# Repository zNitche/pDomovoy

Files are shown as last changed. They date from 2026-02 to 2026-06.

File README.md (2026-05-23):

# pDomovoy

pDomovoy (pD) - room intrusion detection system

### Description
Some time ago I built a [sleepwalking detection and prevention system](https://github.com/zNitche/sleepwalker). It served its purpose good but extensive setup (smartwatch + raspberry Pi 4 + wiring) and the fact that in previous years I've traveled a lot and stayed at many different hotels made me rethink that design.

Then this idea came to my mind, dedicated devices, with long lasting battery life, travel safe (no strong magnets, detachable battery), that serves as `sleepwalker` did but also provides a way to make sure your room's doors stays closed when you sleep (in short nobody enters and leaves without triggering the alarm).

So let's build 2 devices system connected via BLE using C and `pico-sdk`.

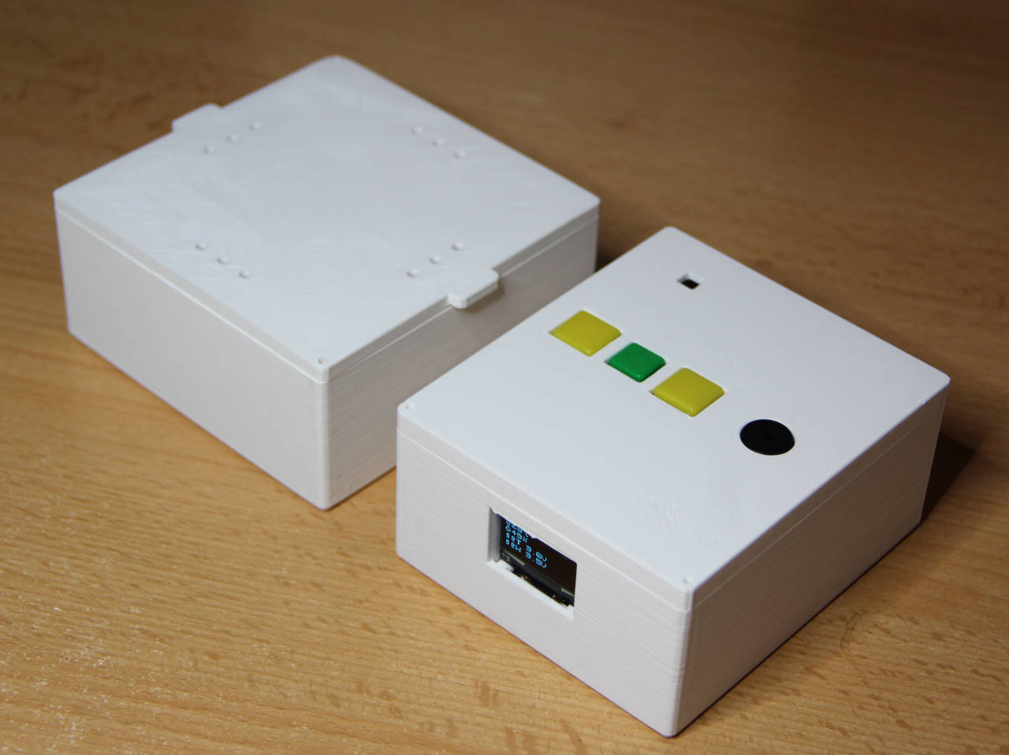
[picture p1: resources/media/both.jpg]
both


### Modules breakdown

#### Warden

##### Description
Heavy lifting device, after initialization (by button push or `Trumpet`) placed against the door, if device's position / orientation changes (or if paired with `trumpet` and connection is lost), the alarm will be activated.

Triggered alarm can by disabled by:
- pushing button 5 times
- using `Trumpet's` control panel

##### Assembly
Setup is quite simple, but due to lack of my PCB production capacities, everything had to be assembled using prototype boards + point to point wiring, anyway it looks like this:

- 2x 30x70 mm prototype 2-side boards, some wires, socket for glass tube fuse and cell holder for 18650 battery

- TP4056 (with DW01a for cell protection) for 18650 LI-ION charging (connected via 1A fuse)
- LED and buzzer connected via BC337 transistor for 5V supply and 3.3V control line, connected via 440R resistor to Raspberry Pi Pico W (probably should add 3.3V zener diode to logic line as a extra protection, but due to reasons mentioned earlier I did not)
- Button connected via 440R resistor to MCU
- 2k2 + 2k2 resistors as voltage divider (with ratio 1/2) connected to battery and MCU ADC as voltmeter used for checking battery level
- ADXL345 accelerometer connected to RPI Pico's 3.3V line and I2C 1
- MCU powered via 5V step-up DC converter
- 220uF capacitors added to Pico's 5V input & step-up converter's input
- 1uF capacior added in parrel to the buzzer for eliminating voltage spikes while generating tone

- 3D printed case, circuit boards mounted using 4x 2mm and 4x 3mm screws
- 2x 2mm screws for case closing

##### Photos
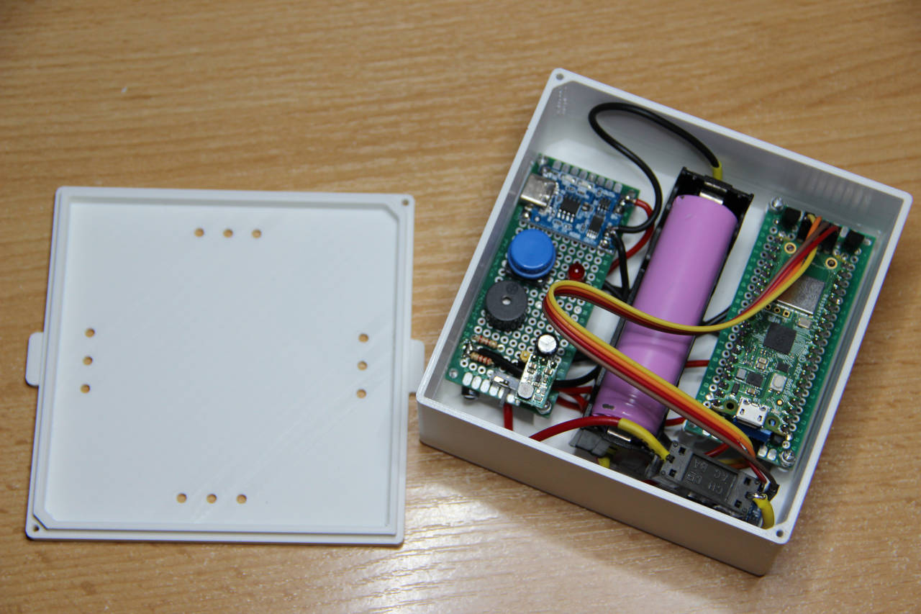
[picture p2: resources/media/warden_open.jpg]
warden_open


#### Trumped
##### Description
Remote panel for whole system with buttons controls and oled display

###### Features
- secure communication with `warden` over BLE with MAC addresses filtering
- `warden's` alarm state management & data preview (battery voltage & alarm state)
- AHT20 humidity & temperature readings
- built in buzzer for alarm
- integrated with SSD1306 screen for data presentation

###### Display pages
1. home page

- aht20 based temperature & humidity
- `trumpet's` & `warden's` battery voltage
- alarm state

2. time stats page

- time since boot
- time since `warden` has been connected
- time since alarm has been armed

3. versions page

shows `trumpet's` & `warden's` version (if `warden` is connected)

###### trumpet's alarm
`trumpet` is equiped with built in buzzer serving as alarm (the same 5v powered buzzer as in `warden`), it will be activated in below cases:

- `warden's` alarm is triggered
- `warden's` alarm in in standby mode and it's connection with `trumpet` has been lost

##### Assembly
the same situation as in `warden's` case, good old prototype boards + point to point wiring, setup looks like this:

- 1x 60x80 mm + 1x 20x80 mm prototype 2-side boards, some wires, socket for glass tube fuse and cell holder for 18650 battery

- TP4056 (with DW01a for cell protection) for 18650 LI-ION charging (connected via 1A fuse)
- Alarm buzzer connected via BC337 transistor for 5V supply and 3.3V control line, connected via 330R resistor to MCU
- 10uF capacior (should be 1uF as in `warden` but due to mistake it is what it is) added in parrel to the buzzer for eliminating voltage spikes while generating tone
- Buttons connected via 330R resistors to MCU
- display & temperature sensor connected to i2c0 and powered via MCU's internal 3.3v
- 1k + 3k3 resistors as voltage divider (with ratio 0.75) connected to battery and MCU ADC as voltmeter used for checking battery level
- MCU powered via 5V step-up DC converter
- 220uF capacitors added to Pico's 5V input & step-up converter's input
- 3D printed case, circuit boards mounted using 10x 2mm and 2x 3mm screws

##### Photos
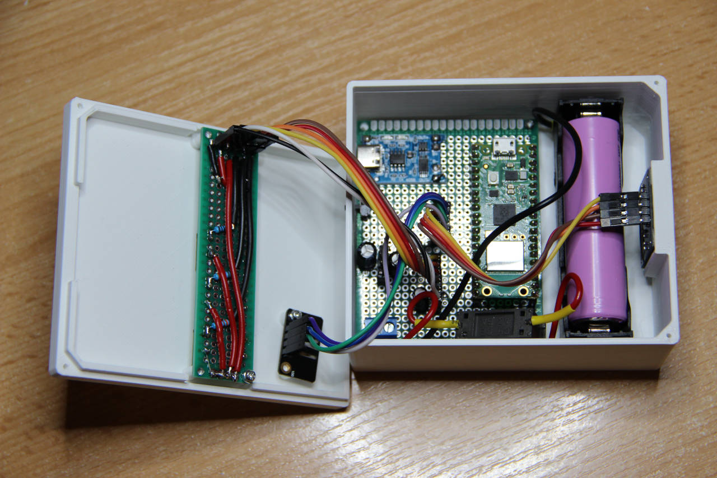
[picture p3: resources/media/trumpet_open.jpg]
trumpet_open


### Setup

1. get pico-sdk
```
mkdir -p ~/SDKs/pico-sdk
cd ~/SDKs/pico-sdk
git clone -b "2.2.0" --single-branch https://github.com/raspberrypi/pico-sdk.git 2.2.0
```

2. initialize pico-sdk dependencies
```
cd ~/SDKs/pico-sdk/2.2.0
git submodule update --init
```

3. initialize project dependencies
```
git submodule update --init
```

4. config setup

###### create config.cmake
```
cp config.cmake.template config.cmake
```

###### fill it's content (if using warden & trumpet)

- set PD_WARDEN_BT_MODE_ENABLED to true
- set PD_WARDEN_BT_MAC to warden's MAC address
- set PD_TRUMPET_BT_MAC to warden's MAC address

5. open project in devcontainer
6. setup project

```
cmake -S . -B build
```

or for debug mode

```
cmake -DDEBUG=1 -S . -B build
```

7. build
```
cd build
make
```

8. flash device with generated `.uf2` file (`trumpet` / `warden`)

### Extra

#### auto copying of `.uf2` file to MCU.
```
sh copy_uf2.sh ./build/warden.uf2 /Volumes/RPI-RP2
```

#### Connect to device
```
screen /dev/tty1
```

to exit 
```
CTRL + A -> CTRL + \
```

### Dependencies
- [pico-sdk](https://github.com/raspberrypi/pico-sdk)

- [ADXL345](https://github.com/zNitche/pico-c-adxl345)
- [SSD1306](https://github.com/zNitche/pico-c-ssd1306)
- [AHT20](https://github.com/zNitche/pico-c-aht20)

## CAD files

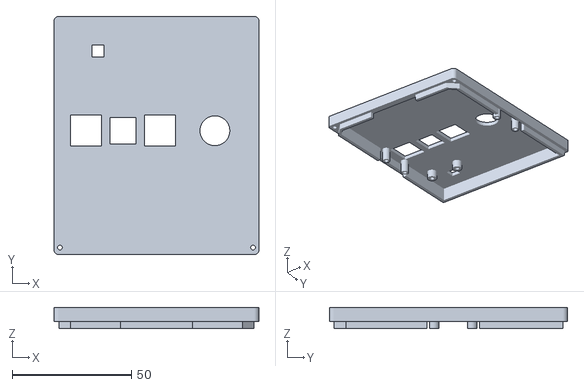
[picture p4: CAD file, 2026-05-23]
resources/3d_models/trumpet/top_mk1.stl
86.0 x 100.0 x 9.00

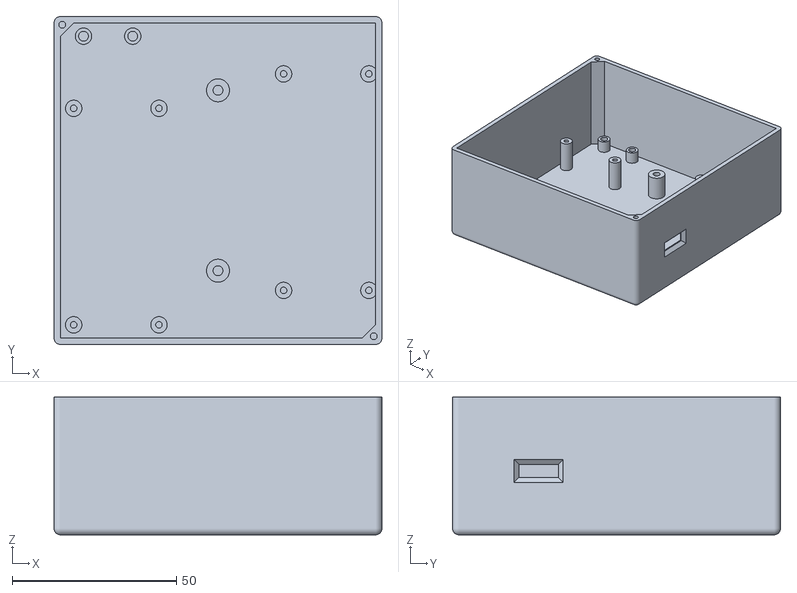
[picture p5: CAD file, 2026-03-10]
resources/3d_models/warden/case_mk2.stl
100.0 x 100.0 x 42.0

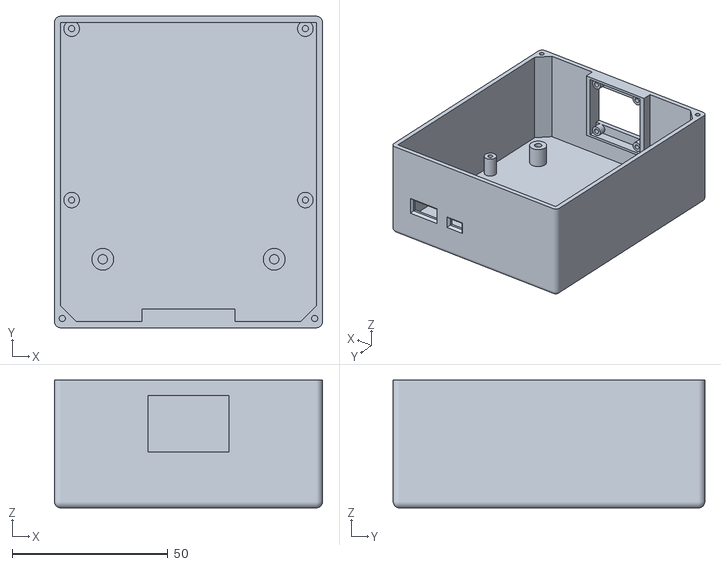
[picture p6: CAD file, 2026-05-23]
resources/3d_models/trumpet/bottom_mk1.stl
86.0 x 100.0 x 41.0

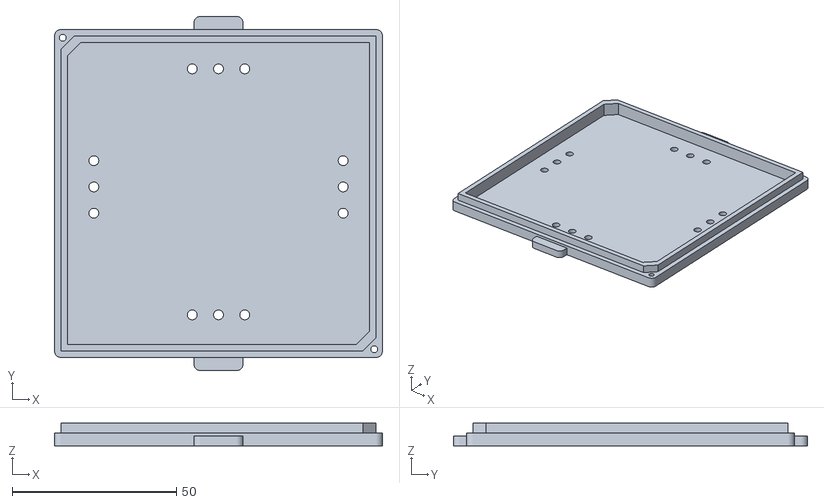
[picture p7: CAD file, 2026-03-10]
resources/3d_models/warden/top_cover_mk2.stl
100.0 x 108.0 x 7.00

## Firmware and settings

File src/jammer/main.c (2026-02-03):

#include <stdio.h>

#include "pico_adxl345/adxl345.h"
#include "hardware/gpio.h"
#include "hardware/pwm.h"
#include "pico/cyw43_arch.h"
#include "pico/stdlib.h"

const int STATUS_LED_PIN = 13;
const int BUZZER_PIN = 14;
const int ACTION_BUTTON_PIN = 12;

bool alarm_on = false;

void buzzer_pwm_call_irq() {
  static int fade = 0;
  static bool going_up = true;

  pwm_clear_irq(pwm_gpio_to_slice_num(BUZZER_PIN));

  if (going_up) {
    ++fade;
    if (fade > 255) {
      fade = 255;
      going_up = false;
    }
  } else {
    --fade;
    if (fade < 0) {
      fade = 0;
      going_up = true;
    }
  }

  pwm_set_gpio_level(BUZZER_PIN, fade * fade);
}

void init_buzzer_pwm() {
  gpio_set_function(BUZZER_PIN, GPIO_FUNC_PWM);
  uint slice_num = pwm_gpio_to_slice_num(BUZZER_PIN);

  pwm_clear_irq(slice_num);
  irq_set_exclusive_handler(PWM_DEFAULT_IRQ_NUM(), buzzer_pwm_call_irq);

  pwm_config config = pwm_get_default_config();
  pwm_config_set_clkdiv(&config, 1);
  pwm_init(slice_num, &config, true);
}

void enable_buzzer_pwm() {
  uint slice_num = pwm_gpio_to_slice_num(BUZZER_PIN);

  irq_set_enabled(PWM_DEFAULT_IRQ_NUM(), true);
  pwm_set_irq_enabled(slice_num, true);
}

void disable_buzzer_pwm() {
  uint slice_num = pwm_gpio_to_slice_num(BUZZER_PIN);

  irq_set_enabled(PWM_DEFAULT_IRQ_NUM(), false);
  pwm_set_irq_enabled(slice_num, false);
  pwm_set_gpio_level(BUZZER_PIN, 0);
}

void button_callback(uint gpio, uint32_t events) {
  if (gpio == ACTION_BUTTON_PIN) {
    if (events == 8) {
      printf("alarm trigger\n");

      if (alarm_on) {
        disable_buzzer_pwm();
        alarm_on = false;
      } else {
        enable_buzzer_pwm();
        alarm_on = true;
      }
    }
  }
}

int main() {
  stdio_init_all();

  int rc = cyw43_arch_init();
  hard_assert(rc == PICO_OK);

#ifdef DEBUG
  // waiting for input
  getchar();
#endif

  printf("jammer...\n");

  // BUZZER
  init_buzzer_pwm();

  // BUTTON
  gpio_init(ACTION_BUTTON_PIN);
  gpio_set_dir(ACTION_BUTTON_PIN, GPIO_IN);
  gpio_pull_down(ACTION_BUTTON_PIN);
  gpio_set_irq_enabled_with_callback(ACTION_BUTTON_PIN, GPIO_IRQ_EDGE_RISE,
                                     true, &button_callback);

  // LED
  gpio_init(STATUS_LED_PIN);
  gpio_set_dir(STATUS_LED_PIN, true);

  // ADXL345
  ADXL345I2C adxl345_i2c = {i2c0, 0x53, 0, 1};

  adxl345_setup_i2c(adxl345_i2c);
  sleep_ms(250);

  bool connected = adxl345_check_connection(adxl345_i2c);

  printf("connected: %d\n", connected);

  enum ADXL345Ranges sensor_range = RANGE_4G;
  adxl345_set_measurements_range(adxl345_i2c, sensor_range);

  adxl345_start_measurements(adxl345_i2c);

  while (true) {
    gpio_put(STATUS_LED_PIN, true);
    sleep_ms(250);
    gpio_put(STATUS_LED_PIN, false);
    sleep_ms(250);

    if (connected) {
      float accel[3] = {0.0};
      adxl345_get_readings(adxl345_i2c, accel);

      printf("Acc. X = %f, Y = %f, Z = %f\n", accel[0], accel[1], accel[2]);

      sleep_ms(200);
    }
  }

  adxl345_stop_measurements(adxl345_i2c);

  return 0;
}

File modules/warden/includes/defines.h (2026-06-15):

#pragma once

#ifndef DEBUG
#define DEBUG 0
#endif

#define PD_WAIT_FOR_ALARM_ARM 15

#define PD_ACCELERATION_CHANGE_TRIGGER_FACTOR 0.3
#define PD_ACCELERATION_READINGS_COUNT 15
#define PD_ACCELERATION_READINGS_DELAY 100

#define PD_ACCELERATION_INITIAL_READINGS_COUNT 15
#define PD_ACCELERATION_INITIAL_READINGS_DELAY 200

// pins
#define PD_ADXL345_SDA_PIN 0
#define PD_ADXL345_SCL_PIN 1
#define PD_STATUS_LED_PIN 15
#define PD_BUZZER_PIN 16
#define PD_ACTION_BUTTON_PIN 18
#define PD_VOLTMETER_ADC_PIN 28
#define PD_VOLTMETER_ADC_ID 2

// button actions
#define CLICK_DEBOUNCE_TIME 1000

#define MIN_TIME_BETWEEN_CLICKS_FOR_ACTION 1500
#define CONTINOUS_CLICKS_TO_DISABLE_ALARM 5

// battery stats
#define BATTER_VOLTAGE_READINGS 30
#define MIN_BATTERY_VOLTAGE 3.3

// alarm buzzer
// tweaked to my buzzers, might need additional tweaks for different ones
#define PD_ALARM_BUZZER_DELAY_MS 300
#define PD_ALARM_BUZZER_ACTIVE_TIME_MS 100
#define PD_ALARM_BUZZER_HIGH_VALUE 2500
#define PD_ALARM_BUZZER_HIGH_VALUE_DEBUG 1000

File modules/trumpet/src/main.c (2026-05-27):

#include <stdbool.h>

#include "../includes/callbacks.h"
#include "../includes/core_0.h"
#include "../includes/defines.h"
#include "../includes/globals.h"
#include "../includes/voltmeter.h"
#include "../includes/bluetooth/core.h"
#include "hardware/adc.h"
#include "pdomovoy_common/button.h"
#include "pdomovoy_common/bluetooth.h"
#include "pdomovoy_common/debug_print.h"
#include "pdomovoy_common/pwm.h"
#include "pdomovoy_common/version.h"
#include "pdomovoy_common/voltmeter.h"
#include "pico/cyw43_arch.h"
#include "pico/stdlib.h"

void init_gpio_peripherals() {
     // BUZZER
    setup_alarm_pwm_irq_callback(PD_BUZZER_PIN, alarm_buzzer_irq_callback);

    // NAVIGATION BUTTONS
    init_button_irq(PD_PREVIOUS_BUTTON_PIN, true);
    init_button_irq(PD_APPLY_BUTTON_PIN, true);
    init_button_irq(PD_NEXT_BUTTON_PIN, true);

    gpio_set_irq_callback(&gpio_irq_callback);
}

void init_voltmeter() {
    init_adc_voltmeter(PD_VOLTMETER_ADC_PIN);
    start_voltmeter_bg();
}

int main() {
    stdio_init_all();

    if (DEBUG) {
        // DEBUG waiting for input
        getchar();
    }

    if (cyw43_arch_init()) {
        printf("failed to initialise cyw43\n");
        return 1;
    }

    debug_print("[pD - TRUMPET] %s\n", TRUMPET_VERSION);

    adc_init();

    init_gpio_peripherals();
    init_voltmeter();

    init_ble();
    turn_bluetooth_on();

    // core_0 for device handling
    core_0();

    return 0;
}

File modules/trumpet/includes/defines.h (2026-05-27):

#pragma once

#ifndef DEBUG
#define DEBUG 0
#endif

// display
#define PD_SCREEN_SAVER_AFTER 20000

// pins
#define PD_PREVIOUS_BUTTON_PIN 17
#define PD_APPLY_BUTTON_PIN 16
#define PD_NEXT_BUTTON_PIN 14

#define PD_VOLTMETER_ADC_PIN 28
#define PD_VOLTMETER_ADC_ID 2
#define PD_BUZZER_PIN 18

// i2c
#define PD_AHT20_I2C i2c0
#define PD_AHT20_SDA_PIN 0
#define PD_AHT20_SCL_PIN 1

#define PD_SSD1306_I2C i2c0
#define PD_SSD1306_SDA_PIN 0
#define PD_SSD1306_SCL_PIN 1

// button actions
#define CLICK_DEBOUNCE_TIME 1000

#define MIN_TIME_BETWEEN_CLICKS_FOR_ACTION 1500

// alarm buzzer
#define PD_ALARM_BUZZER_DELAY_MS 600
#define PD_ALARM_BUZZER_ACTIVE_TIME_MS 300

// intended to be placed next to bed, keep it quiet (I used 10uF capacitor
// instead of 1uF), therefore a higher value
#define PD_ALARM_BUZZER_HIGH_VALUE 8500
#define PD_ALARM_BUZZER_HIGH_VALUE_DEBUG 2000

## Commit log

2026-01-15 build: pico sdk setup
2026-02-01 build: added pico-c-adxl345 as git submodule
2026-02-01 feat: added pico-c-adxl345 lib
2026-02-02 fix: proper directory of station -> main.c
    [main.c]
2026-02-02 feat: basic support for button, accelerometer & led
2026-02-02 feat: enabled adxl345 for jammer
    [main.c]
2026-02-03 refactor: moved jammer & station to modules directory
    [main.c]
2026-02-04 feat: jammer - split project into separated files
    [button.c, main.c]
2026-02-04 feat: jammer - added action button callbacks with debounce
    [button.c, callbacks.c, main.c]
2026-02-04 fix: jammer - button callback imports tweaks
    [main.c]
2026-02-04 refactor: extracted buzzer to separated .c file
    [buzzer.c, main.c]
2026-02-05 fix: fixed setting buzzer irq
    [buzzer.c, callbacks.c, main.c]
2026-02-05 refactor: buzzer.c internal cleanup
    [buzzer.c]
2026-02-05 fix: action_button_callback - setting alarm state
    [callbacks.c]
2026-02-05 feat: proper buzzer initialization
    [callbacks.c, main.c]
2026-02-06 refactor: utils - renamed buzzer to pwm
    [callbacks.c, main.c, pwm.c]
2026-02-07 fix: main.c & core_0.c - added missing includes
    [main.c]
2026-02-09 refactor: moved count_clicks_in_row() to button.c
2026-02-10 build: libs - updated pico-c-adxl345 to v1.2.0
2026-02-10 refactor: DeviceStatus items - naming changes
2026-02-10 feat: blocking led blink
2026-02-10 refactor: jammer - renamed handlers.c -> delegates.c
    [callbacks.c]
2026-02-10 feat: led_blink - background bliks using timers
2026-02-10 feat: jammer - core_1 - status led for standby init
    [callbacks.c]
2026-02-10 refactor: moved led_blink.c to utils dir
2026-02-11 refactor: removed status led logic from core_1
2026-02-11 feat: led_blink.c - blink_untill_start() - added init guard
2026-02-11 feat: jammer - alarm_buzzer_irq_callback() proper implementation
    [callbacks.c]
2026-02-12 feat: jammer - switch to pico_cyw43_arch_lwip_threadsafe_background
2026-02-12 feat: jammer - status led blinks
    [button.c, callbacks.c, globals.c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]
2026-02-12 feat: jammer - basic background battery voltmeter
    [globals.c, main.c]
2026-02-17 feat: leds - reclaim blink timer on init
2026-02-17 feat: jammer - blink status led on adxl345 error
2026-02-17 feat: checking battery level + status led integration
2026-02-17 refactor: jammer - extracted battery checking to separated func
2026-02-17 refactor: jammer - status led blink (bg) handling refactoring
2026-02-17 feat: jammer - status led blinks improvements
    [globals.c]
2026-02-17 refactor: jammer - core_0 - moved battery related vars to globals
    [globals.c]
2026-02-19 refactor: jammer - callbacks related typing tweaks
    [callbacks.c]
2026-02-19 fix: cancelling currently running status led timer for blocking blinks
2026-02-22 feat: extracted adxl345 i2c related pins to defines
2026-02-22 feat: moved voltmeter related magic numbers to defines
2026-02-22 refactor: changed pins bindings
    [defines.h]
2026-02-23 feat: battery level checking improvements
2026-02-23 feat: jammer - callbacks.c - logging improvements
    [callbacks.c]
2026-02-24 fix: debug_print() - replaced printf with vprintf
2026-02-24 feat: jammer - version.h
    [main.c]
2026-02-24 refactor: renamed jammer to warden
    [button.c, callbacks.c]
2026-02-27 refactor: removed blocking delay from onboard led blink interrupt
2026-03-08 fix: _blink_onboard_led_cb() setting proper led state
2026-03-09 refactor: warden - changed accelerometer readings for alarm trigger
2026-03-09 feat: core_1 - checkign for accelerometer based alarm trigger improvements
2026-03-10 feat: warden - added 3d models
    [case_mk2.stl, top_cover_mk2.stl]
2026-03-10 feat: added accelerometer_reading type
2026-03-10 refactor: changed array based acceleration reading representation with accelerometer_reading
2026-03-11 refactor: changed root directory of 3d models
    [case_mk2.stl, top_cover_mk2.stl]
2026-04-12 feat: added pico-c-ssd1306 lib as submodule
2026-04-18 feat: added pico-c-aht20 lib as submodule
2026-04-18 build: updated pico-c-adxl345 to v1.2.2
2026-04-19 feat: trumpet basic action button setup
2026-04-19 feat: ButtonDebounceCtx
2026-04-19 refactor: renamed accelerometer_reading to AccelerometerReading
2026-04-20 refactor: removed button_callback type
2026-04-20 refactor: commons - extracted setting gpio irq for button callback
2026-04-20 feat: trumpet - action buttons callbacks
2026-04-21 build: updated pico-c-ssd1306 to v1.0.2
2026-04-21 feat: trumpet - i2c devices initialization utils
2026-04-21 feat: trumpet - core0 screen & aht20 sensor usage
2026-04-21 feat: trumpet - pages switching using buttons
2026-04-22 feat: basic env sensors page handler
2026-04-22 feat: trumpet - sensors page - rendering aht20 readings
2026-04-23 refactor: voltmeter extracted to commons
2026-04-23 refactor: voltmeter added voltage_divider_ratio arg to read_adc_voltage()
2026-04-23 refactor: common voltmeter - pick adc before reading
2026-04-23 feat: trumpet - voltmeter integration
2026-04-25 feat: warden - ble working example (connecting to server & printing status)
2026-04-28 feat: warden - ble_service_context - is_connected prop
2026-04-30 refactor: warden - onboard led blink improvements
2026-04-30 feat: trumpet gatt - added warden battery voltage
2026-04-30 refactor: warden - timers delays (negative ones)
2026-04-30 refactor: remove queue timer
2026-04-30 fix: warden bt defines - handlers uuids
    [defines.h]
2026-04-30 refactor: warden - client_handler - printing uuid16
2026-05-01 fix: warden - voltmeter proper voltage divider ratio
2026-05-01 refactor: warden main - voltmeter init cleanup
2026-05-01 refactor: button debounce handling tweaks
2026-05-01 fix: button debounce - workaround for wrong irq triggers
    [button.c]
2026-05-02 fix: trumpet - g_warden_version allocation
    [globals.c]
2026-05-04 feat: warden - moved pd_bt_queue_processing_loop to repeating timer
2026-05-05 feat: trumpet - pages handling - env sensor reading buffering
2026-05-06 feat: trumpet - action button - block alarm controls if current page != home
2026-05-07 feat: bluetooth - switched to security LEVEL_4
2026-05-07 feat: warden - extended wait for alarm arm to 15 seconds
2026-05-07 feat: trumpet - ble - added MAC filtering on client's connection
2026-05-08 feat: trumpet - alarm buzzer callback handler
    [callbacks.c, defines.h, main.c]
2026-05-08 feat: trumpet - alarm buzzer handling
    [globals.c]
2026-05-18 fix: warden - tweaked voltmeter conversion factor
2026-05-18 feat: warden - moved alarm pwm related settings to defines + tweaked its values
2026-05-23 feat: added trumpet's case stl files
    [bottom_mk1.stl, top_mk1.stl]
2026-05-28 fix: commons - helpers added missing pico/time.h include
2026-05-28 refactor: trumpet - replaced g_screen_saver_timer with function in main display loop
    [globals.c]
2026-06-01 refactor: trumpet - pages - home page - battery rendering improvements
2026-06-15 refactor: warden - extracted accelerometer readings config to warden's defines
2026-06-15 feat: trumpet - improved ble connection params for lower power usage
